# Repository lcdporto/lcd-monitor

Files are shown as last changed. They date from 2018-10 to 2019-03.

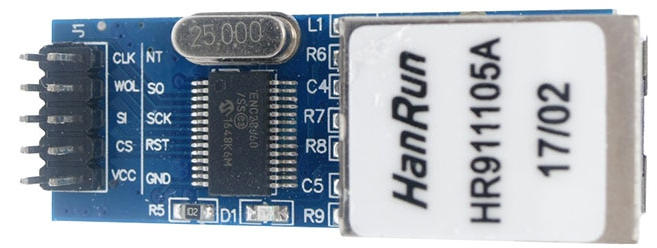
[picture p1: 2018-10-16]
pcb/Mini-ENC28J60-Ethernet-LAN-Network-Module-AVR-SPI-PIC-STM32-LPC.jpg

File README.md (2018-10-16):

# LCD Monitor

Project to create a Facilities Monitor and Access Control System  for a shared space.

As our work space is shared by several people, we want to have the greatest flexibility and at the same time security and responsibility, access control is a challenge that we have long tried to solve.

We resolved to cannibalize the current alarm and create a new one whose programming is much more flexible.

---

The progress of this project can be tracked (in Portuguese) in a [blog post](https://blog.lcdporto.org/project-lcd-monitor/) at our blog.

---

## Brief description

The console will be run by a Arduino and an API running on a server, the Arduino will handle all the sensors, keypad and buzzers independently.

The API (probably using Django REST) to communicate events and receive instructions.

After receiving new programming the API will pass it to the Arduino via  ethernet.

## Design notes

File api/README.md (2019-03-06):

Requisitos
==========

Dois focos principais:

* Autenticação
* Monitorização

Autenticação
------------

* autenticação de utilizadores
  * Suporte para "Single Sign On (SSO)"
* gestão de códigos por utilizador
* ativação/desativação remota (via web) do alarme
* atribuição de códigos temporários
* Pode ser delegada para um serviço externo
  * tem sempre que haver suporte para funcionar como backup

Monitorização
-------------

* Registar:
  * Alterações de estado
    * Sensores
    * Porta
* Alarmistca:
  * Fonte:
    * Sensores
      * Transição
      * Nivel
    * Porta
      * Transição
  * Tipos de alarmes:
    * Silenciosos
    * Sonoros
    * Remotos

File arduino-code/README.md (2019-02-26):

# Arduino Code

Code running on the Arduino controlling the LCD Monitor.

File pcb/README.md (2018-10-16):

# LCD Monitor - PCB

## Requirements

* Pass 12v to the sensors and feed return signal throught optocouplers to the Arduino
* Signaling using LEDs (armed/clear/alarm/zones)
* PCB headers to the [keypad](16-Key-4-x-4-Membrane-Keypad.jpg)  
* PCB headers to hold Arduino Nano or, build an Arduino on the board
* Feed 5v to the Arduino
* PCB headers to [ethernet module](Mini-ENC28J60-Ethernet-LAN-Network-Module-AVR-SPI-PIC-STM32-LPC.jpg)
* Charging circuit to a 12v battery
* Anti-tampering push button on the board

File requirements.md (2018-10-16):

# Requisitos

Cada componente tem uma descrição mais detalhada dos requisitos na sua pasta

## Versão 0

* gestão de códigos por utilizador
* desativação remota do alarme
* códigos temporários

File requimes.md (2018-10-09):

# Requisitos

## Versão 0

* gestão de códigos por utilizador
* desativação remota do alarme
* códigos temporários

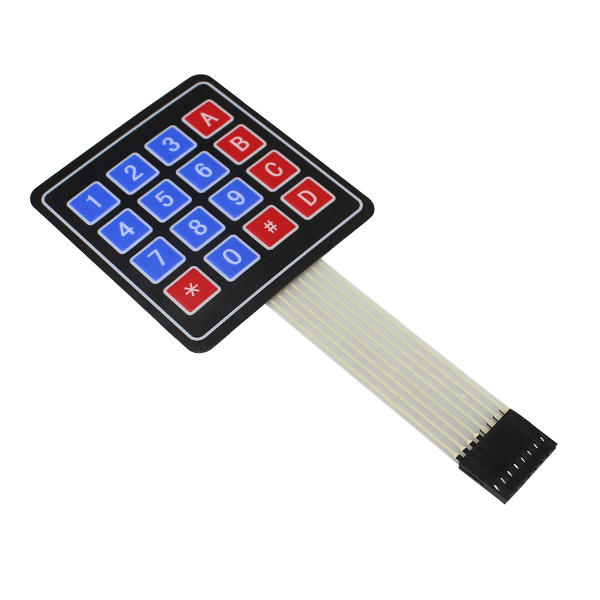
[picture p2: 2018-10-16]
pcb/16-Key-4-x-4-Membrane-Keypad.jpg

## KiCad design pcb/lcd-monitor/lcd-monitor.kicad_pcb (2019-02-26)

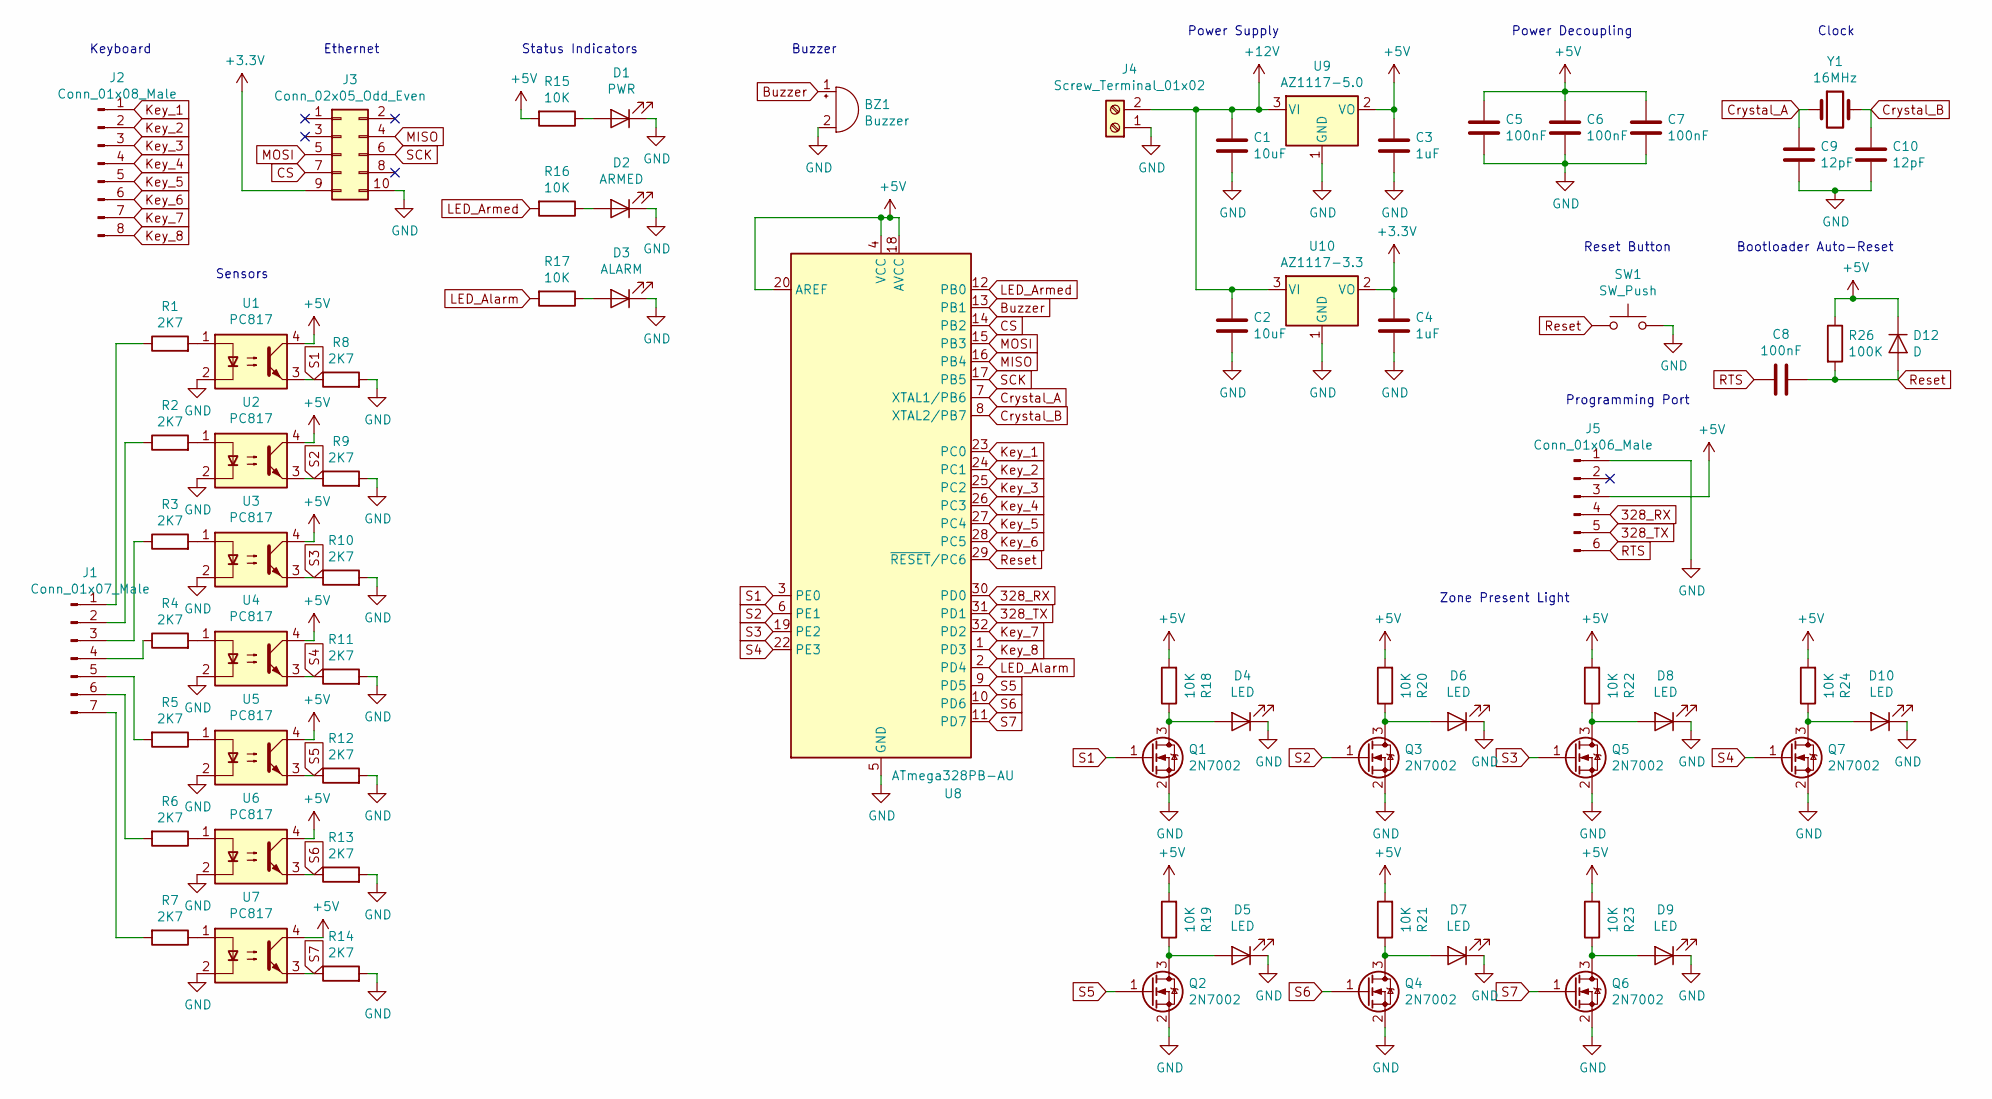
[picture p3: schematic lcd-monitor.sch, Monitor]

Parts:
BZ1: Buzzer; Buzzer_12x9.5RM7.6
C1, C2: 10uF; C_0805_2012Metric
C3, C4: 1uF; C_0805_2012Metric
C5, C6, C7, C8: 100nF; C_0805_2012Metric
C9, C10: 12pF; C_0805_2012Metric
D1: PWR; LED_0805_2012Metric
D2: ARMED; LED_0805_2012Metric
D3: ALARM; LED_0805_2012Metric
D4, D5, D6, D7, D8, D9, D10: LED; LED_0805_2012Metric
D12: D; D_0805_2012Metric
J1: Conn_01x07_Male; PinHeader_1x07_P2.54mm_Vertical
J2: Conn_01x08_Male; PinHeader_1x08_P2.54mm_Vertical
J3: Conn_02x05_Odd_Even; PinSocket_2x05_P2.54mm_Vertical
J4: Screw_Terminal_01x02; TerminalBlock_Altech_AK300-2_P5.00mm
J5: Conn_01x06_Male; PinHeader_1x06_P2.54mm_Vertical
Q1, Q2, Q3, Q4, Q5, Q6, Q7: 2N7002; SOT-23
R1, R2, R3, R4, R5, R6, R7, R8, R9, R10, R11, R12, R13, R14: 2K7; R_0805_2012Metric
R15, R16, R17, R18, R19, R20, R21, R22, R23, R24: 10K; R_0805_2012Metric
R26: 100K; R_0805_2012Metric
SW1: SW_Push; SW_SPST_FSMSM
U1, U2, U3, U4, U5, U6, U7: PC817; DIP-4_W7.62mm
U8: ATmega328PB-AU; TQFP-32_7x7mm_P0.8mm
U9: AZ1117-5.0; SOT-223
U10: AZ1117-3.3; SOT-223
Y1: 16MHz; Crystal_SMD_3225-4Pin_3.2x2.5mm

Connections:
328_RX: J5.4, U8.30 (PD0)
328_TX: J5.5, U8.31 (PD1)
+3V3: C4.1, J3.9, U10.2 (VO)
+5V: C3.1, C5.1, C6.1, C7.1, D12.1 (K), J5.3, R15.2, R18.2, R19.2, R20.2, R21.2, R22.2, R23.2, R24.2, R26.1, U1.4, U2.4, U3.4, U4.4, U5.4, U6.4, U7.4, U8.4 (VCC), U8.18 (AVCC), U8.20 (AREF), U9.2 (VO); also elsewhere on the board
+12V: C1.1, C2.1, J4.2, U9.3 (VI), U10.3 (VI)
Buzzer: BZ1.1 (-), U8.13 (PB1)
CS: J3.7, U8.14 (PB2)
Crystal_A: C9.1, U8.7 (XTAL1/PB6), Y1.1
Crystal_B: C10.1, U8.8 (XTAL2/PB7), Y1.2
GND: BZ1.2 (+), C1.2, C2.2, C3.2, C4.2, C5.2, C6.2, C7.2, C9.2, C10.2, D1.1 (K), D2.1 (K), D3.1 (K), D4.1 (K), D5.1 (K), D6.1 (K), D7.1 (K), D8.1 (K), D9.1 (K), D10.1 (K), J3.10, J4.1, J5.1, Q1.2 (S), Q2.2 (S), Q3.2 (S), Q4.2 (S), Q5.2 (S), Q6.2 (S), Q7.2 (S), R8.2, R9.2, R10.2, R11.2, R12.2, R13.2, R14.2, SW1.2, U1.2, U2.2, U3.2, U4.2, U5.2, U6.2, U7.2, U8.5 (GND), U8.21 (GND), U9.1 (GND), U10.1 (GND); also elsewhere on the board
Key_1: J2.1, U8.23 (PC0)
Key_2: J2.2, U8.24 (PC1)
Key_3: J2.3, U8.25 (PC2)
Key_4: J2.4, U8.26 (PC3)
Key_5: J2.5, U8.27 (PC4)
Key_6: J2.6, U8.28 (PC5)
Key_7: J2.7, U8.32 (PD2)
Key_8: J2.8, U8.1 (PD3)
LED_Alarm: R17.2, U8.2 (PD4)
LED_Armed: R16.2, U8.12 (PB0)
MISO: J3.4, U8.16 (PB4)
MOSI: J3.5, U8.15 (PB3)
unnamed: D1.2 (A), R15.1
unnamed: D2.2 (A), R16.1
unnamed: D3.2 (A), R17.1
unnamed: D4.2 (A), Q1.3 (D), R18.1
unnamed: D5.2 (A), Q2.3 (D), R19.1
unnamed: D6.2 (A), Q3.3 (D), R20.1
unnamed: D7.2 (A), Q4.3 (D), R21.1
unnamed: D8.2 (A), Q5.3 (D), R22.1
unnamed: D9.2 (A), Q6.3 (D), R23.1
unnamed: D10.2 (A), Q7.3 (D), R24.1
unnamed: J1.1, R1.1
unnamed: J1.2, R2.1
unnamed: J1.3, R3.1
unnamed: J1.4, R4.1
unnamed: J1.5, R5.2
unnamed: J1.6, R6.2
unnamed: J1.7, R7.2
unnamed: R1.2, U1.1
unnamed: R2.2, U2.1
unnamed: R3.2, U3.1
unnamed: R4.2, U4.1
unnamed: R5.1, U5.1
unnamed: R6.1, U6.1
unnamed: R7.1, U7.1
RTS: C8.2, J5.6
Reset: C8.1, D12.2 (A), R26.2, SW1.1, U8.29 (~RESET~/PC6)
S1: Q1.1 (G), R8.1, U1.3, U8.3 (PE0)
S3: Q5.1 (G), R10.1, U3.3, U8.19 (PE2)
S5: Q2.1 (G), R12.1, U5.3, U8.9 (PD5)
SCK: J3.6, U8.17 (PB5)

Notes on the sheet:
Clock
Power Decoupling
Bootloader Auto-Reset
Power Supply
Reset Button
Programming Port
Keyboard
Ethernet
Status Indicators
Buzzer
Sensors
Zone Present Light

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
Board: 2 copper layers, 74 parts (0 on the bottom side), 57 nets, no tracks yet.

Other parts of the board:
D11: LED; LED_0805_2012Metric
Q8: 2N7002; SOT-23
R25: 10K; R_0805_2012Metric

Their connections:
+5V: R25.2; also elsewhere on the board
GND: D11.1, Q8.2; also elsewhere on the board
unnamed: D11.2, Q8.3, R25.1

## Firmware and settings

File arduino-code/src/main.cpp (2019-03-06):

/*
 *
 *  Uses https://playground.arduino.cc/code/keypad
 *
 *
 */

#include <Arduino.h>
#include <Keypad.h>
#include <elapsedMillis.h>
#include <EEPROM.h>
#include "main.h"
#include "configuration.h"

Configuration conf;

/******************
 * PIN asignments
 */

// used by the keypad
byte rowPins[] = {A7,A6,A5,A4};
byte colPins[] = {A3,A2,A1,A0};

// active zones
const byte ZONES[3] = { 5, 6 };

// the LEDs
const byte LED_ALARM = 2;
const byte LED_ARMED = 4;

// the buzz
const byte BUZZER = 3;

// External alarm
const byte E_ALARM = 7;

// Anti-Tampering
const byte ANTI_TAMPERING = 9;

/*
 * end PIN assigments
 *********************/

/* starting keypad */
// @TODO should this go into the function that andles the keypad
const char keys[4][4] = {
  {'1','2','3','A'},
  {'4','5','6','B'},
  {'7','8','9','C'},
  {'*','0','#','D'}
};
Keypad keypad = Keypad( makeKeymap(keys), rowPins, colPins, 4, 4 );

// Sound Codes
const byte sndStart=1;
const byte sndCancel=2;
const byte sndKeyPress=3;
const byte sndOK=4;
const byte sndNotOK=5;


/* zoneType: 0 = Instant Alarm; 1 = Deferred Alarm ); */
#define INSTANT_ALARM  1
#define DEFERRED_ALARM 0
bool zoneType[2] = {
  0,
  0
};

/* deferTime, time in seconds before a Deferred Alarm goes on */
byte deferTime = 15;

/* deferredAlarmState: 0 = no activity; 1 = in Deferred Alarm countdown */
bool deferredAlarmState = 0;
elapsedMillis deferredAlarmStart;

/* onAlarm: full blown Alarm in progress */
bool onAlarm = 0;
bool inInput=false;
bool isArmed=false;



int keyTone = 900;
int keyToneDuration = 50;
// =========================================================================88|

void setup() {

  Serial.begin(9600); while (!Serial) { ; }
  Serial.println();

  Serial.println();
  Serial.print("1st Byte: ");
  Serial.println(EEPROM.read(0));
  Serial.print("2nd Byte: ");
  Serial.println(EEPROM.read(1));
  Serial.print("3rd Byte: ");
  Serial.println(EEPROM.read(2));

  byte *myMAC = conf.macAddress();

  for ( uint i = 0; i < sizeof(ZONES) - 1; i++ ) {
    pinMode(i,INPUT);
  }
  pinMode(LED_ALARM, OUTPUT); digitalWrite(LED_ALARM, HIGH);
  pinMode(LED_ARMED, OUTPUT); digitalWrite(LED_ARMED, HIGH);

  sound(sndStart);
  isArmed=true;
  delay(200);
}


/**
 * Da loop
 *
 * Faking multitasking, call all functions has fas as possible
 *
 */
void loop() {

  heartBeat();
  readZones();
  readKeypad();

  ledKeeper();
  soundKeeper();


}

// =========================================================================88|





//


/**
 * void hearBeat()
 *
 * give visual feedback that the software is running by temporarely inverting
 * the status of LED_ARMED
 */
#define HEART_BEAT_SLEEP 1000
#define HEART_BEAT_DURATION 50  // must be lower than HEART_BEAT_SLEEP
void heartBeat()
{
  static elapsedMillis timeElapsed;
  static bool onBeat = false; // if a heartbeat is currently ocorring

  if ( ( onBeat && timeElapsed > HEART_BEAT_DURATION ) || ( timeElapsed > HEART_BEAT_SLEEP ) )
  {
    onBeat = !onBeat;
    digitalWrite( LED_ARMED, !digitalRead( LED_ARMED ) );
    timeElapsed = 0;
  }

}


/* Read All Zones and trigger Alarm Events */
void readZones() {
  for ( int zone = 0; zone < sizeof(ZONES); zone++ ) {

    if( ( !digitalRead(ZONES[zone]) ) && isArmed ) {

      if ( zoneType[zone] = INSTANT_ALARM ) {
        onAlarm=true;
      } else {
        deferredAlarmState=true;
        deferredAlarmStart = 0;
      }

    }
  }

  // Serial.print("deferredAlarmState: ");
  // Serial.println(deferredAlarmState);
  if (
    deferredAlarmState &&
    ( deferredAlarmStart >  deferTime ) &&
    ( ! onAlarm )
  ) {
    onAlarm=true;
  }
}

/*
* Tries to Disrm the alarm if a correct password is given
*/
void disarmAlarm(String pass){
  Serial.print("Testing Password: ");
  Serial.println(pass);
  for(uint32_t p : conf.wallet){
    if (p == pass.toInt()){
      sound(sndOK);
      onAlarm = 0;
      isArmed = false;
      return;
    }
  }
  Serial.println("Wrong Password!");
  sound(sndNotOK);
}

/*
* Adds a new password
*/
void addPass(String pass){
  Serial.print("Adding Password: ");
  Serial.println(pass);
  for(uint32_t p : conf.wallet){
    if (p == pass.toInt()){
      Serial.println("Password already exists, nothing changed");
      return;
    }
  }
  conf.wallet[conf.npass++] = pass.toInt();
  conf.updateEEPROM();
}

/*
* Removes a password if it exists
*/
void remPass(String pass){
  Serial.print("Removing Password: ");
  Serial.println(pass);

  for(uint8_t i = 0; i < conf.npass; i++){
    if (conf.wallet[i] == pass.toInt()){
      conf.wallet[i] = 0;
      return;
    }
  }
  Serial.println("Password not found, nothing changed");
}

/* Read the Keypad and trigger events */
void readKeypad() {
  const byte IdleTimeBetweenKeyPresses = 10;
  static String inputString = "";
  static unsigned long lastKeypress;

  char key = keypad.getKey();

  if (key != NO_KEY){
    lastKeypress = millis();
    sound(sndKeyPress);
    inputString += key;

    Serial.print("Key Pressed: ");
    Serial.println(key);

    // Special keys
    if(key == 'A') {
    }
    if(key == '#') inputString = "";

    if(inputString.length() >= 6){
      disarmAlarm(inputString);
      inputString = "";
    }
  }


/*
  // if idle time passes cancel input state
  if ( (long)( millis() - lastKeypress )  <
       (long)( IdleTimeBetweenKeyPresses * 1000 ) ) {
    inputString = "";
    inInput = false;
    // sound(sndCancel);
  }
*/
}

void ledKeeper() {
  /*
  digitalWrite(LED_ARMED,isArmed);
  digitalWrite(LED_ALARM,onAlarm);
  */
}

void sound(byte sndCode) {
  tone(BUZZER,500,100);
}

void soundKeeper() {
  #define kks 500
}

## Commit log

2018-10-16 api: Criar pasta e README
    Actualizar os requisitos principais com uma referência para os de cada
    componente.
2018-10-16 adds basic requirements for the PCB
2018-10-18 PCB Schematic Alpha Version
    [lcd-monitor.kicad_pcb, lcd-monitor.sch]
2018-10-18 Buzzer through PWM
    [lcd-monitor.sch]
2018-10-19 Fix Optocoupler Resistor Values
    [lcd-monitor.sch]
2018-10-19 Assign Footprints
    [lcd-monitor.sch]
2018-10-19 Fix Ethernet Header
    [lcd-monitor.sch]
2018-10-19 Assign footprint for the new Ethernet header
    [lcd-monitor.sch]
2018-10-19 Remove unused CTS signal
    [lcd-monitor.sch]
2018-10-19 PCB first desing (not working)
    [lcd-monitor.kicad_pcb]
2018-10-24 adds first tests to arduino code
2018-11-03 Add zone status led
    [lcd-monitor.kicad_pcb, lcd-monitor.sch]
2018-11-03 Fix status LEDs
    [lcd-monitor.sch]
2019-02-28 resolves compile errors after migration to platformIO
    [main.cpp]
2019-03-04 WIP: starts class 'configuration'
    [configuration.h]
2019-03-05 adds conf of mac address
    [configuration.h]
2019-03-05 Set Anti-Tampering Pin
2019-03-05 Password Storage and Authentication
    [configuration.h]
2019-03-05 Moved initial alarm password to a define statement
    [configuration.h]
2019-03-06 Added debug serial prints and EEPROM password add, remove and update.
    [configuration.h]
2019-03-06 removes test function 'sherwood'
    [configuration.h]
2019-03-06 implements use of EEPROM_PASSWORD_BEGIN_ADDRESS
    [configuration.h]
2019-03-06 api: Activar REST-Framework no django
